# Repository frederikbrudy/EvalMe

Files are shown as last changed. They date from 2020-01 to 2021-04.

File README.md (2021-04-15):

#EvalMe: Exploring the Value of New Technologies for In Situ Evaluation of Learning Experiences

Repository accompanying the ACM CHI 2021 publication **EvalMe: Exploring the Value of New Technologies for In Situ Evaluation of Learning Experiences.** 
Auhtors: *Susan Lechelt, Frederik Brudy, Nicolai Marquardt, Yvonne Rogers.*
Published in Proceedings of the ACM Conference on Human Factors in Computing Systems 2021 (ACM CHI '21), May 8–13, 2021, Yokohama, Japan.
DOI: https://doi.org/10.1145/3411764.3445749

#Contents
- [EvaleMe-Desktop](EvaleMe-Desktop) contains the code for the Electron app for the EvalMe Desktop application
- [EvalMe-Hardware](EvalMe-Hardware) contains the Arduino code for both Sender and Receiver
  - [EvalMe-encoderButton-Neopixelring-rf95-client-Mega.V2](EvalMe-Hardware\EvalMe-encoderButton-Neopixelring-rf95-client-Mega.V2) is the code for the sender
  - [EvalMe-rf95_reliable_datagram_server.V2](EvalMe-Hardware\EvalMe-rf95_reliable_datagram_server.V2) is the code for the receiver
  - [Case-Receiver](EvalMe-Hardware/Case-Receiver) contains the 3D printing files for the receiver case. 
  - [Case-Sender](EvalMe-Hardware/Case-Sender) contains the 3D printing files for the sender case.

# EvalMe hardware

The system consists of two parts, one Sender (large box) and one Receiver part (small box) as described in the publication. The receiver is simply an Arduino Uno, with a LoRa shield stacked on top of it, and mounted to the bottom part of the small box.

The sender needs more assembling, which is detailed below.

It might make sense to assemble some / all of these on a breadboard before soldering and test whether the code and hardware is working correctly.

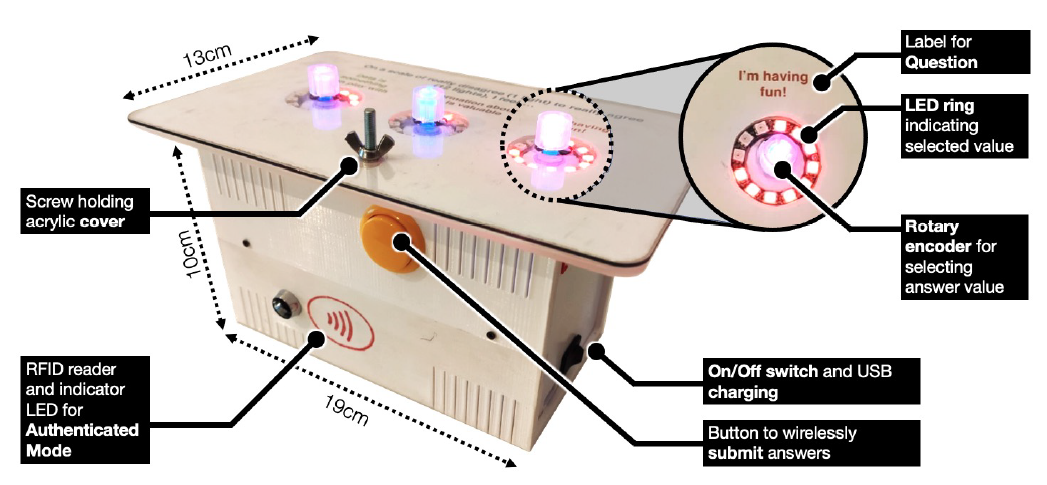
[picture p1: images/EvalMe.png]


https://www.youtube.com/watch?v=0FNkCVAWlew

## Parts for sender

The sender device consists of multiple components:

- Arduino Mega
- RFID Module (Adadfruit PN532 Breakout Board)
- PowerBoost 1000C
- Toggle switch for power
- 3x 12 LED Neopixel rings
- 3x Rotary Encoder with RGB LED and pushbutton
- Arduino Mega ProtoShield to solder the connections
- LoRa shield. Stacks on top of the Mega Proto Shield.
- Push button
- 5mm blue LED and silver LED holder. 100 Ohm+ resistor
- Several 2-wire click connectors (for LED, PowerBoost Enable, PowerBoost-to-Arduino connection, pushbutton)
- Several 3-wire click connectors (for 5V and GND for rotary encoder, Neopixel rings)
- Several 6-wire click connectors (for data connection for rotary encoder, RFID shield)

## Cases
The 3D printing files can be found in [Case-Receiver](EvalMe-Hardware/Case-Receiver) as well as [Case-Sender](EvalMe-Hardware/Case-Sender)

## General structure
The Arduino Mega and the PowerBoost are screwed to the bottom part of the Sender casing. There are mounts in the base for both. Small screws should be used.

The proto shield (see below) is stacked on top of the Arduino. The LoRa shield is stacked on top of the proto shield.

The RFID module is placed upright towards the front where the RFID symbol is. Use e.g. double-sided tape or Velcro to hold it in place. The battery is placed behind the RFID module.

A large blue LED is screwed with the silver LED mount to the hole to the left of the RFID symbol. Connect using a minimum 100 Ohm resistor between LED and power.

A push button is connected to the right of the RFID symbol. 

The connections between the Proto Shield and all other components should be made with click-connectors. They are either 2-wire, 3-wire, or 6-wire and have a male and female part. The wires coming from e.g. the female connector are soldered to the proto shield, the wires coming from e.g. the male connector are soldered to the components.
 The connection holes for the wires on each side are labelled with numbers on the back that correspond to the same connection on the other clip. You need to crimp the wires and clip then into the male/female connectors. 

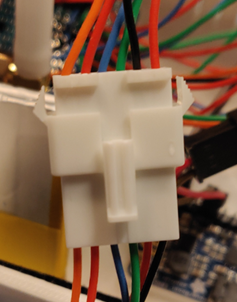
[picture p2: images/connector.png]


## Proto Shield

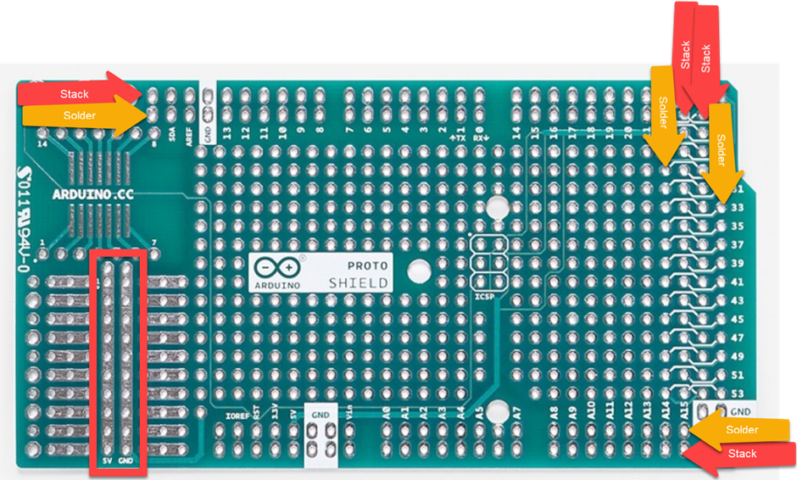
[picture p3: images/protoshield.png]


Generally, all connections to components should be made through the Proto Shield (see image above). Sacking headers must be soldered to the Proto Shield. Stacking headers (see following image) are the ones with long legs at the bottom (to stack on top of the Arduino), and female connectors at the top (to stack other shields on top, i.e. the LoRa shield).

The stacking headers are soldered to the rows / columns of through-holes marked in red &quot;Stack&quot; above (basically so that they&#39;ll stack properly on top of the Arduino). Wires connecting to the click-connectors (which then connect to other components) are then soldered to the through-holes marked with &quot;Solder&quot;.

Note that the Proto Shield has many through-holes connected to GND and 5V on the left (marked with the red rectangle). These can be used to connect the GND and 5V of pushbuttons, LED rings, and RFID board, etc.

Note the block in the front, that&#39;s the one to use for the centre connection of the LoRa module (see description below).

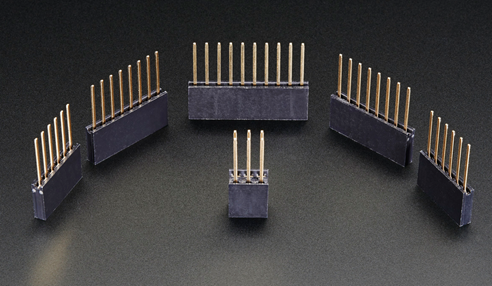
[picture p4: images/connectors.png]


## LoRa shield

The LoRa shield is stacked on top of the Proto Shield. The LoRa shield requires the six pins in the middle of the board (circled in red below, labelled with ICSP) to connected to the Arduino as well, so these headers must be soldered to the Proto Shield as well. There are 2x3 headers (see image above) that fit here. **Attention:** Here the female connectors are facing down towards the Arduino board and the male pins are facing up—that&#39;s the opposite way as all other pins, so the headers must be adjusted accordingly.

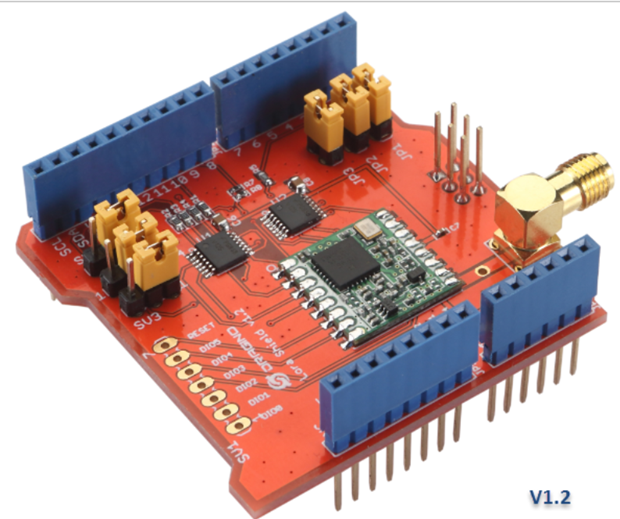
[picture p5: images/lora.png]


## PowerBoost 1000C

Connect the GROUND and ENable pin on the PowerBoost to the toggle switch. This allows to turn the 5V output of the PowerBoost off/on. There should be black switches that fit nicely into the side-plate of the large case. Note: It might be that the labelling on the switch is inverted to the behaviour of the PowerBoost (i.e. when the switch is set to I the output is off, when set to O the output is on). In this case carefully use a carpenter knife and scratch out the labelling on the button.

Connect the other GND of the PowerBoost to the Arduino GND and the 5V to Vin on the Arduino ( **NOT** to 5V on the Arduino).

PowerBoost GND -> One toggle switch pin
 PowerBoost EN -> Other toggle switch pin
 Make these connections using a 2-wire click connector

PowerBoost GND -> Arduino GND
 PowerBoost 5V -> Arduino Vin
 You can make the 5V/GND connection using jumper wires or a 2-wire click connector

You might need to solder headers on to the PowerBoost.

Make sure you&#39;re using the 1000C, not the 500 and not the basic. The C indicates Charger, so it has a micro USB connection to charge the connected battery and/or power directly without a battery. Connect the battery only after you finished the general assembly of everything.

Some of the PowerBoosts are faulty and the LED labelled LOW lights up when the output is switched to off (not to be confused with the CHARGE LED). In this case gently cut the connection of the LOW LED using a carpenter knife or similar to turn it off entirely.

## Rotary encoders

Not all the encoders are yet soldered to the breakout boards. When assembling them please note that the red breakout boards are two-sided, labelled RG and RGB. We have RGB LEDs inside the pushbuttons, so use the RGB side: When assembling the rotary encoders / pushbuttons they should be inserted into the RGB side of the breakout board. In other words, when holding the button/encoder normally up, the RGB side of the breakout board is facing up. Some of them are already assembled, so just check how it&#39;s done there.

The following indicates the connections from the encoders to the Arduino.
 For the GND and 5V connections you can use a 3-wire click connector shared between the three encoders. For the other connections you can use a 6-wire click connector fore each button.
 For example, the 6-wire A-1 connector means a 6-wire click connector A, hole 1.

### Button 1

| | Encoder | Proto Shield | Connector |
|---|---|---|---|
| These pins are on the side with the 3 pins | B | 22 | 6-wire A-1 |
| | C | GROUND | 3-wire click connector shared between all encoders |
| | A | 18 | 6-wire A-2 |
| These pins are on the side with the 5 pins | R | 15 | 6-wire A-3 |
| | G | A14 | 6-wire A-4 |
| | SW | 14 | 6-wire A-5 |
| | B | 16 | 6-wire A-6 |
| | + | 5 Volt | 3-wire click connector shared between all encoders |

<!--![images/wiring-button1.png](images/wiring-button1.png)-->

### Button 2
| | Encoder | Proto Shield | Connector |
|---|---|---|---|
| These pins are on the side with the 3 pins | B | 23 | 6-wire B-6 |
| | C | GROUND | 3-wire click connector shared between all encoders |
| | A | 19 | 6-wire B-6 |
| These pins are on the side with the 5 pins | R | 29 | 6-wire B-6 |
| | G | 28 | 6-wire B-6 |
| | SW | 31 | 6-wire B-6 |
| | B | 30 | 6-wire B-6 |
| | + | 5 Volt | 3-wire click connector shared between all encoders |

<!-- ![images/wiring-button2.png](images/wiring-button2.png)--> 

### Button 3

| | Encoder | Proto Shield | Connector |
|---|---|---|---|
| These pins are on the side with the 3 pins | B | 24 | 6-wire C-6 |
| | C | GROUND | 3-wire click connector shared between all encoders |
| | A | 3 | 6-wire C-6 |
| These pins are on the side with the 5 pins | R | 32 | 6-wire C-6 |
| | G | 33 | 6-wire C-6 |
| | SW | 34 | 6-wire C-6 |
| | B | 35 | 6-wire C-6 |
| | + | 5 Volt | 3-wire click connector shared between all encoders |

<!--![images/wiring-button3.png](images/wiring-button3.png)-->

After assembling, uploading the code, and testing the mapping of the rotary encoder to the NeoPixel rings you might need to switch around which click connector from which button connects to which corresponding connector on the proto shield. But that&#39;s just a matter of flipping them to another.

## RFID module

Use the following PIN mapping. Images below indicate the pins on the RFID module. Use a 6-wire click connector.

| **RFID module PIN** | **Arduino PIN / Proto Shield** |
| --- | --- |
| 2 | 46 |
| 3 | 47 |
| SDA (3 pins to the right of PIN 13) | 20 (SDA) |
| SCL (next to the above) | 21 (SCL) |
| GND | GND (can be to the dedicated GND section on the left of the proto shield) |
| 5V | 5V (can be to the dedicated GND section on the left of the proto shield) |

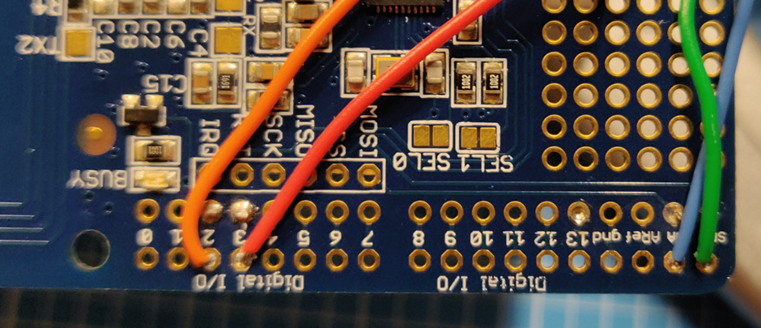
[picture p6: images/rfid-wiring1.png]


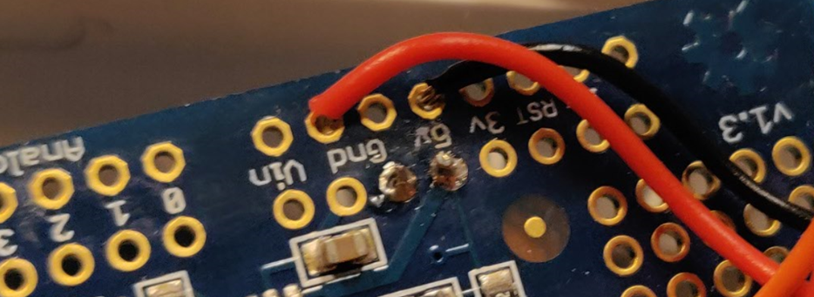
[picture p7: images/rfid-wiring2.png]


## NeoPixel LED rings

There are 3 NeoPixel rings with 12 LEDs each. They are connected in series to Arduino PIN 40, 5V, and GND. To allow assembly, there should be a 3-wire click connector used between each of them, so that DO (data out) of the previous ring is connected to DI (data in) of the next.

Arduino PIN 40 -> Ring 1 DI (data in)

Ring 1 DO (data out) -> Ring 2 DI

Ring 2 DO -> Ring 3 DI

5V &amp; GND from Arduino to the first ring 5v&amp;GND next to DI.
 5V &amp; GND next to DO of ring 1 then to the 5V and GND next to the DI of the ring 2 and so on.

Use small screws to mount the rings to the case. You might need to drill one of the holes again, as the holes on the case might not fit perfectly. **Note:** When using metal screws, they might short circuit two of the pixels and cause a reset of the Arduino / erratic behaviour. Use small drops of superglue to create a small plastic film over the metal parts that are touched by the screws. Let it dry and then insert the screws. I have done this already for the rings used in the half-assembled prototype.

## Pushbutton and LED

A large (5mm) blue LED is screwed with the silver LED mount to the hole to the left of the RFID symbol. Add a minimum 100 Ohm resistor between LED and Arduino.

A push button is connected to the right of the RFID symbol. Use one with a flat backside, not the one that sticks out \&gt;3cm. There should be one ready on the desk. No resistor needed for the button

| **Part** | **Arduino / Proto Shield** |
| --- | --- |
| LED short leg | GND (add a >100 Ohm resistor in series) |
| LED long leg | 38 |
| Button PIN 1 | 42 |
| Button PIN 2 | GND |

Code for the Arduino can be found in the folder [EvalMe Hardware](EvalMe Hardware)

Once everything is assembled, upload code as follows:

- [EvalMe-encoderButton-Neopixelring-rf95-client-Mega.V2](EvalMe-Hardware\EvalMe-encoderButton-Neopixelring-rf95-client-Mega.V2) to the Arduino Mega in the Sender
- [EvalMe-rf95_reliable_datagram_server.V2](EvalMe-Hardware\EvalMe-rf95_reliable_datagram_server.V2) to the Arduino Uno in the Receiver

You can test it by opening the serial monitor on the receiver / Uno and power up the sender. Then enter the following text in serial monitor and send it to the Arduino Uno:

`REQUIRE_NO_AUTH` and `SET_COUNTER_MAX:12` 
This will set some initial parameters in the Mega's EEPROM.
 Afterwards play around with the encoders to check whether the LED&#39;s on the rings light up correctly. Press the button to send the data. It should be displayed in the Serial Monitor on the receiver / Uno.

To test the RFID, send the following to the receiver's / Uno's serial monitor `REQUIRE_AUTH` 
 All LEDs on top of the sender should turn off and the blue LED should blink. Use e.g. your student ID card to &quot;log in&quot; and then the encoders are usable.

## License
MIT license

**EvalMe: Exploring the Value of New Technologies for In Situ Evaluation of Learning Experiences.**
*Susan Lechelt, Frederik Brudy, Nicolai Marquardt, Yvonne Rogers.*
Published in Proceedings of the ACM Conference on Human Factors in Computing Systems 2021 (ACM CHI '21), May 8–13, 2021, Yokohama, Japan.
DOI: https://doi.org/10.1145/3411764.3445749

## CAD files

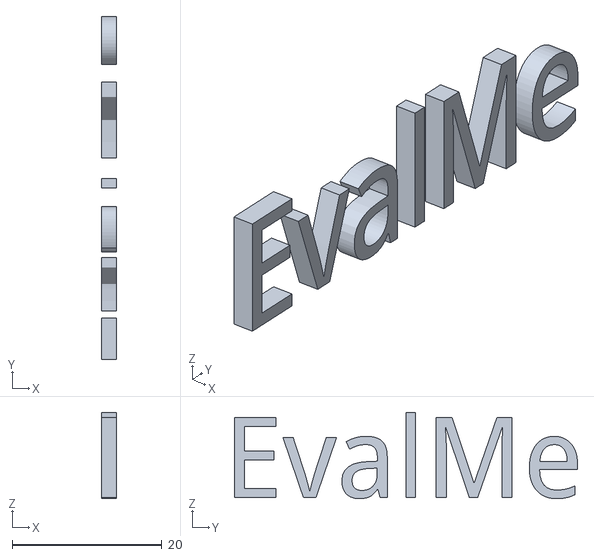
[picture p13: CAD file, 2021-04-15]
EvalMe-Hardware/Case-Receiver/receiver.V1.front.writing-EvalMe.stl
2.02 x 45.8 x 11.6

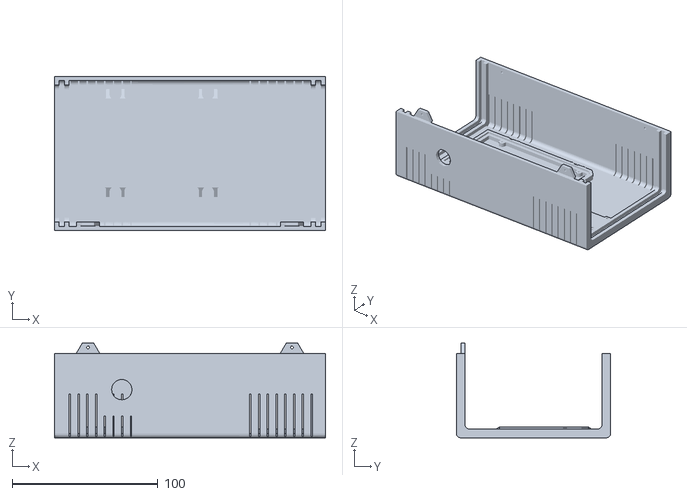
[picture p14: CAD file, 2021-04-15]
EvalMe-Hardware/Case-Sender/U_Box_V103.bottom.V2-without logo.stl
186.0 x 106.0 x 64.9

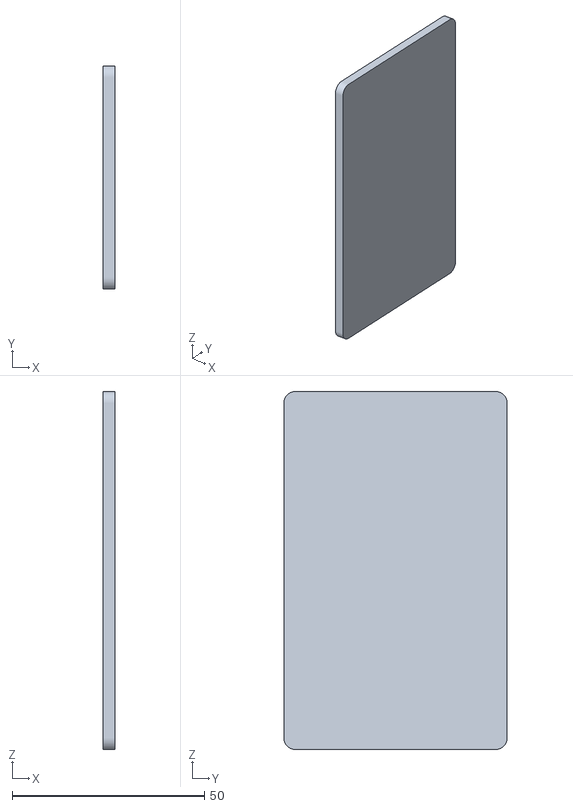
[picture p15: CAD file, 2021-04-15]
EvalMe-Hardware/Case-Receiver/receiver.V1.front.stl
3.00 x 58.1 x 93.1

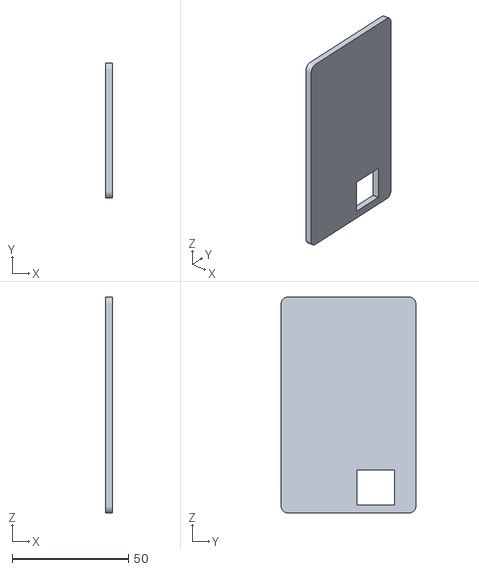
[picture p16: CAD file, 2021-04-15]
EvalMe-Hardware/Case-Receiver/receiver.V1.back-with cutout.stl
3.00 x 58.1 x 93.1

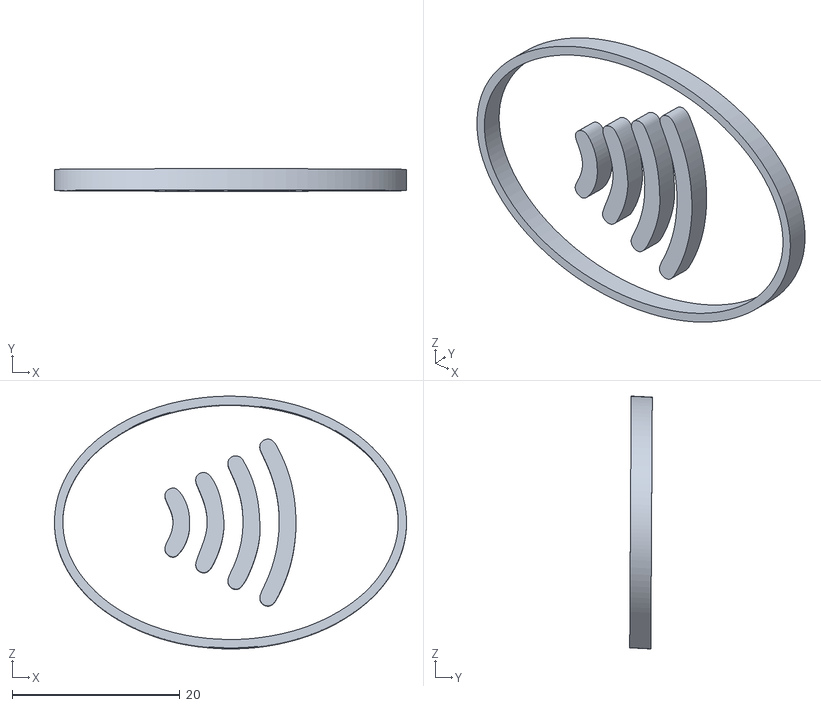
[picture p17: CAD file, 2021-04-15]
EvalMe-Hardware/Case-Sender/U_Box_V103.bottom.V2-only logo.stl
42.0 x 2.70 x 30.1

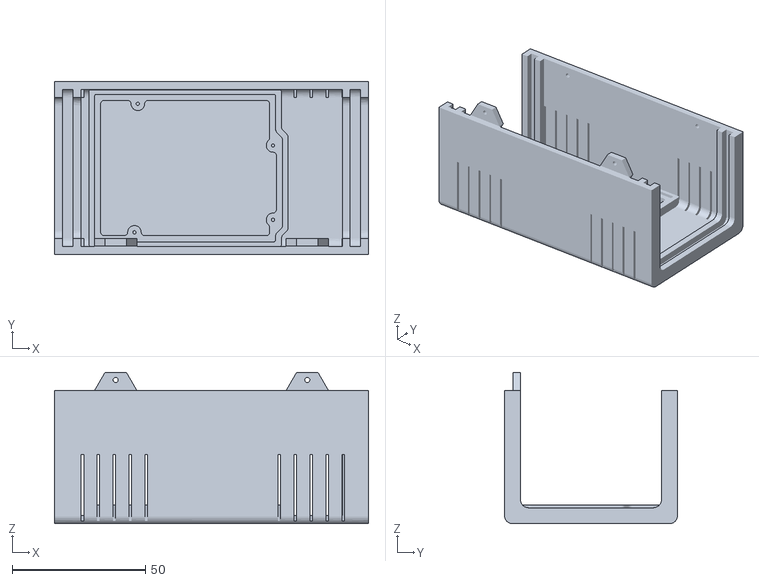
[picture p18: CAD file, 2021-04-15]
EvalMe-Hardware/Case-Receiver/receiver.V1.bottom-with mount.stl
118.0 x 65.0 x 56.9

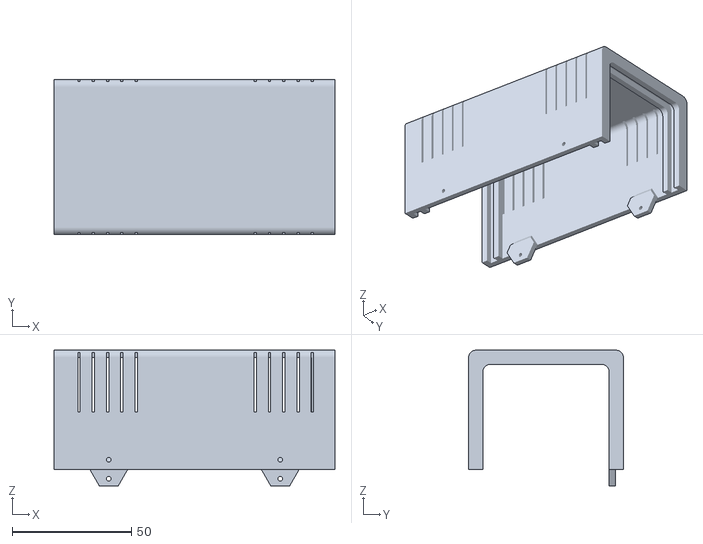
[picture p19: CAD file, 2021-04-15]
EvalMe-Hardware/Case-Receiver/receiver.V1.top.stl
118.0 x 65.0 x 56.9

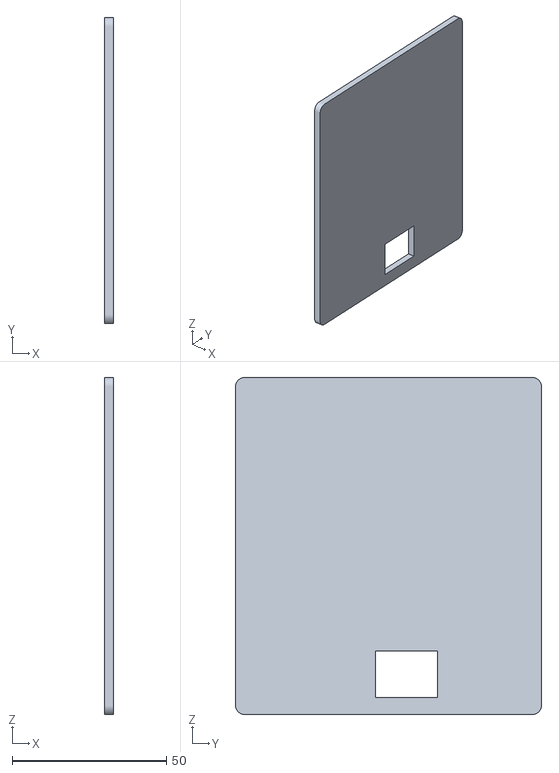
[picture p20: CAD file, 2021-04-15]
EvalMe-Hardware/Case-Sender/U_Box_V103.back.V1.stl
3.00 x 99.1 x 109.1

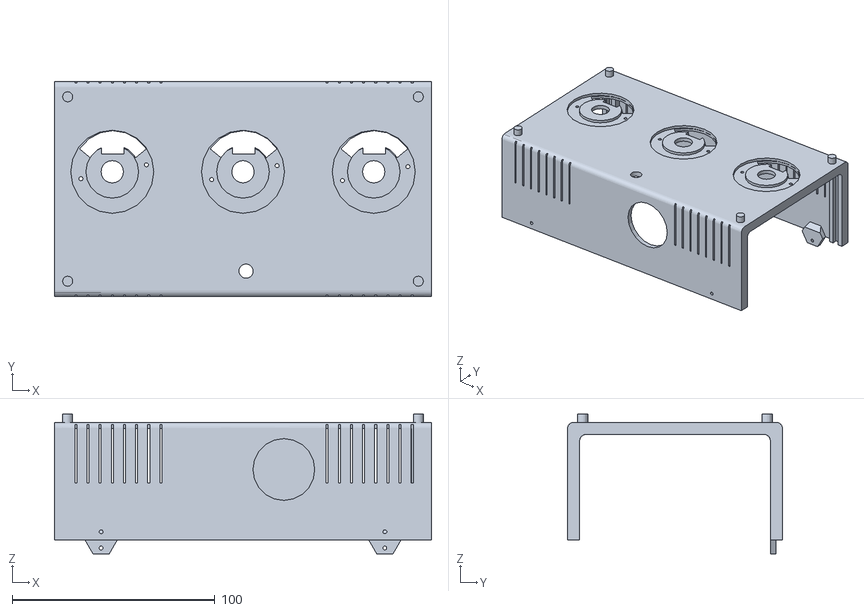
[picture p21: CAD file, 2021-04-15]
EvalMe-Hardware/Case-Sender/U_Box_V103.top.V6.stl
186.0 x 106.0 x 69.0

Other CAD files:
EvalMe-Hardware/Case-Sender/U_Box_V103.front-noFont.V1 with cutouts, no LED-hole.stl
EvalMe-Hardware/Case-Sender/U_Box_V103.front-FontOnly.V1.stl

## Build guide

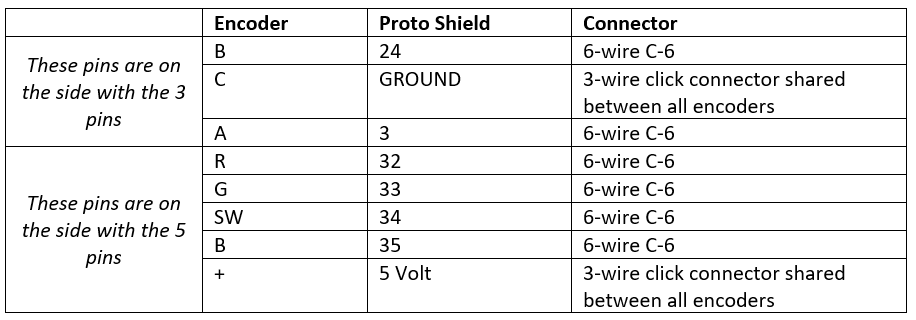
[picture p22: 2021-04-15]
images/wiring-button3.png

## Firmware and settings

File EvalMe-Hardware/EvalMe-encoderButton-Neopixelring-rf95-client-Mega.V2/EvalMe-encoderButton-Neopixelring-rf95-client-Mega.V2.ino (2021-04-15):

// HARDWARE CONNECTIONS
// connect a rotary encoder to your Arduino using these pins:

// Rotary encoder pin A to digital pin 3*
// Rotary encoder pin B to analog pin 3
// Rotary encoder pin C to ground

// This sketch implements software debounce, but you can further
// improve performance by placing 0.1uF capacitors between
// A and ground, and B and ground.

// If you wish to use the RGB LED and button functions of
// SparkFun part number COM-10982, use the following connections:

// Rotary encoder pin 1 (red cathode) to digital pin 10
// Rotary encoder pin 2 (green cathode) to analog pin 1
// Rotary encoder pin 3 (button) to digital pin 4
// Rotary encoder pin 4 (blue cathode) to digital pin 5
// Rotary encoder pin 5 (common anode) to VCC (3.3V or 5V)

// Note that because this is a common anode device,
// the pushbutton requires an external 1K-10K pullDOWN resistor
// to operate.

// * Pins marked with an asterisk should not change because
// they use interrupts on that pin. All other pins can change,
// see the constants below.

// SERIAL MONITOR

// Run this sketch with the serial monitor window set to 9600 baud.

// HOW IT WORKS

// The I/O pins used by the rotary encoder hardware are set up to
// automatically call interrupt functions (rotaryIRQ and buttonIRQ)
// each time the rotary encoder changes states.

// The rotaryIRQ function transparently maintains a counter that
// increments or decrements by one for each detent ("click") of
// the rotary encoder knob. This function also sets a flag
// (rotary_change) to true whenever the counter changes. You can
// check this flag in your main loop() code and perform an action
// when the knob is turned.

// There is also code in the main loop() that keeps track
// of whether the button is currently being held down and for
// how long. This is useful for "hold button down for five seconds
// to power off"-type situations, which cannot be handled by
// interrupts alone because no interrupts will be called until
// the button is actually released.

// Uses the PinChangeInt library by Lex Talionis,
// download from http://code.google.com/p/arduino-pinchangeint/


#define HALT_ON_ERROR false

#include <EEPROM.h> 

////////////////////////////////////////////////
//Rotary encoder with RGB pushbutton
////////////////////////////////////////////////

// Load the PinChangeInt (pin change interrupt) library
#include <PinChangeInt.h>


///////////// confirm button

#define BUTTON_PIN 42

/////////////rotary encoder 1
#define ROT_B 22        // rotary B 
#define ROT_A 18          // rotary A IRQ

#define ROT_LEDR 15      // red LED
#define ROT_LEDG A14     // green LED
#define ROT_SW 14         // rotary puhbutton
#define ROT_LEDB 16       // blue LED

/////////////rotary encoder 2
#define ROT2_B 23        // rotary B 
#define ROT2_A 19          // rotary A IRQ

#define ROT2_LEDR 29      // red LED
#define ROT2_LEDG 28     // green LED
#define ROT2_SW 31         // rotary puhbutton
#define ROT2_LEDB 30       // blue LED

///////////rotary encoder 3

#define ROT3_B 24        // rotary B 
#define ROT3_A 3          // rotary A IRQ

#define ROT3_LEDR 32      // red LED
#define ROT3_LEDG 33     // green LED
#define ROT3_SW 34         // rotary puhbutton
#define ROT3_LEDB 35       // blue LED

// RGB LED colors (for common anode LED, 0 is on, 1 is off)
#define OFF B111
#define RED B110
#define GREEN B101
#define YELLOW B100
#define BLUE B011
#define PURPLE B010
#define CYAN B001
#define WHITE B000


// low battery indicator
#define LBO_PIN 52 // PowerBoost 1000C low battery indicator
#define LOW_BATTERY_LED 53


/////////// confirm button
volatile boolean confirm_button_pressed = false; // will turn true if the button has been pushed
volatile boolean confirm_button_released = false; // will turn true if the button has been released (sets button_downtime)
volatile unsigned long confirm_button_downtime = 0L; // ms the button was pushed before release
static boolean confirm_button_down = false;
static unsigned long int confirm_button_down_start, confirm_button_down_time;

/////////// rotary encoder 1
// Global variables that can be changed in interrupt routines
volatile int rotary_counter = 0; // current "position" of rotary encoder (increments CW)
volatile boolean rotary_change = false; // will turn true if rotary_counter has changed
//volatile boolean button_pressed = false; // will turn true if the button has been pushed
//volatile boolean button_released = false; // will turn true if the button has been released (sets button_downtime)
//volatile unsigned long button_downtime = 0L; // ms the button was pushed before release

// "Static" variables are initalized once the first time
// that loop runs, but they keep their values through
// successive loops.

static unsigned char ledColor = BLUE; //LED color
//static boolean button_down = false;
//static unsigned long int button_down_start, button_down_time;


////////// rotary encoder 2
int counter2_ledsOn = 0;
// Global variables that can be changed in interrupt routines
volatile int rotary2_counter = 0; // current "position" of rotary encoder (increments CW)
volatile boolean rotary2_change = false; // will turn true if rotary_counter has changed
//volatile boolean button2_pressed = false; // will turn true if the button has been pushed
//volatile boolean button2_released = false; // will turn true if the button has been released (sets button_downtime)
//volatile unsigned long button2_downtime = 0L; // ms the button was pushed before release

static unsigned char ledColor2 = BLUE; //LED color
//static boolean button2_down = false;
//static unsigned long int button2_down_start, button2_down_time;



////////// rotary encoder 3
int counter3_ledsOn = 0;
// Global variables that can be changed in interrupt routines
volatile int rotary3_counter = 0; // current "position" of rotary encoder (increments CW)
volatile boolean rotary3_change = false; // will turn true if rotary_counter has changed
//volatile boolean button3_pressed = false; // will turn true if the button has been pushed
//volatile boolean button3_released = false; // will turn true if the button has been released (sets button_downtime)
//volatile unsigned long button3_downtime = 0L; // ms the button was pushed before release

static unsigned char ledColor3 = BLUE; //LED color
//static boolean button3_down = false;
//static unsigned long int button3_down_start, button3_down_time;







////////////////////////////////////////////////
//Neopixel stuff. 
////////////////////////////////////////////////
#include <Adafruit_NeoPixel.h>
int COUNTER_MIN = 0;
int COUNTER_MAX = 12;
/////////// ring 1
#define RING1_NEOPIXEL_PIN 40
#define RING_PIXEL_COUNT 12
#define RING_COUNT 3
int ring1_counter_ledsOn = 0;

/////////// ring 2
//#define RING2_NEOPIXEL_PIN 41
//#define RING2_PIXEL_COUNT 12
int ring2_counter_ledsOn = 0;

/////////// ring 3
//#define RING3_NEOPIXEL_PIN 42
//#define RING3_PIXEL_COUNT 12
int ring3_counter_ledsOn = 0;

Adafruit_NeoPixel rings = Adafruit_NeoPixel(RING_PIXEL_COUNT*RING_COUNT, RING1_NEOPIXEL_PIN, NEO_GRB + NEO_KHZ800);
//Adafruit_NeoPixel ring2 = Adafruit_NeoPixel(RING2_PIXEL_COUNT, RING2_NEOPIXEL_PIN, NEO_GRB + NEO_KHZ800);
//Adafruit_NeoPixel ring3 = Adafruit_NeoPixel(RING3_PIXEL_COUNT, RING3_NEOPIXEL_PIN, NEO_GRB + NEO_KHZ800);



// IMPORTANT: To reduce NeoPixel burnout risk, add 1000 uF capacitor across
// pixel power leads, add 300 - 500 Ohm resistor on first pixel's data input
// and minimize distance between Arduino and first pixel.  Avoid connecting
// on a live circuit...if you must, connect GND first.

uint32_t red = rings.Color(255, 0, 0);
uint32_t green = rings.Color(0, 255, 0);
uint32_t blue = rings.Color(0, 0, 255);
uint32_t purple = rings.Color(128, 0, 128);
uint32_t yellow = rings.Color(255, 100, 0);
uint32_t off = rings.Color(0, 0, 0);
uint32_t white = rings.Color(255, 255, 255);
uint32_t cyan = rings.Color(0, 255, 255);

void setRingPixelColor(uint8_t ringNumber, uint32_t pixelNumber, uint32_t color){
  rings.setPixelColor(pixelNumber+(ringNumber*RING_PIXEL_COUNT), color);
}

void setRingPixelColorAll(uint32_t pixelNumber, uint32_t color){
  for (int ring = 0; ring < RING_COUNT; ring++){
    rings.setPixelColor(pixelNumber+(ring*RING_PIXEL_COUNT), color);
  }
}

void clearRing(uint8_t ringNumber){
  for (int pixelNumber = 0; pixelNumber < RING_PIXEL_COUNT; pixelNumber++){
    rings.setPixelColor(pixelNumber+(ringNumber*RING_PIXEL_COUNT), off);
  }
  rings.show();
}

uint32_t ledColorToNeopixelColor(uint32_t color){
  switch(color){
    case OFF:
      return off;
      break;
    case RED:
      return red;
      break;
    case GREEN:
      return green;
      break;
    case YELLOW:
      return yellow;
      break;
    case BLUE:
      return blue;
      break;
    case PURPLE:
      return purple;
      break;
    case CYAN:
      return cyan;
      break;
    case WHITE:
      return white;
      break;
    default: 
      return red;
      break;
  }
}

////////////////////////////////////////////////
//Buffer stuff. Used when data cannot be sent for later sending. Stores the last ten submissions
////////////////////////////////////////////////
#include "CircularBuffer.h"

// the type of the record is unsigned long: we intend to store milliseconds
// the buffer can contain up to 10 records
// the buffer will use a byte for its index to reduce memory footprint
CircularBuffer<unsigned long, 10> fifo;
CircularBuffer<String, 10> fifoStr;


////////////////////////////////////////////////
//LoRa communication stuff
////////////////////////////////////////////////
// Based on example: rf95_reliable_datagram_client.ino
// Don't forget to set the frequency of the board when using the RadioHead library
//The RadioHead Library simplifies communication between the Arduino Board and the LoRa Shield.
//We can find it here: http://www.airspayce.com/mikem/arduino/RadioHead/ To use it in your project 
//you just have to copy it in your Arduino project folder (next to your main Arduino project file .ino).
//Compile Notice:
//Check if you have set the right frequency:After putting the library in the right place, 
//you have to also modify the frequency to the frequency you want to use, the position of this is
//setFrequency() in the file: arduino-xxx\libraries\RadioHead\RH_RF95.cpp;
//we're using this LoRa Shield: https://wiki.dragino.com/index.php?title=Lora_Shield

#include <RHReliableDatagram.h>
#include <RH_RF95.h>
#include <SPI.h>

#define CLIENT_ADDRESS 5
#define SERVER_ADDRESS 3

// Singleton instance of the radio driver
RH_RF95 driver;
//RH_RF95 driver(5, 2); // Rocket Scream Mini Ultra Pro with the RFM95W

// Class to manage message delivery and receipt, using the driver declared above
RHReliableDatagram manager(driver, CLIENT_ADDRESS);

//uint8_t data[] = "Hello World!";
uint8_t data[64] = "";
// Dont put this on the stack:
uint8_t buf[RH_RF95_MAX_MESSAGE_LEN];

int counter = 0;
#include <string.h>

////////////////////////////////////////////////
// RFID stuff for for the adafrui NFC shield iwth I2C connection
////////////////////////////////////////////////
#include <Wire.h>
#include <Adafruit_PN532.h>
// If using the breakout or shield with I2C, define just the pins connected
// to the IRQ and reset lines.  Use the values below (2, 3) for the shield!
#define PN532_IRQ   46
#define PN532_RESET 47  // Not connected by default on the NFC Shield
// Or use this line for a breakout or shield with an I2C connection:
Adafruit_PN532 nfc(PN532_IRQ, PN532_RESET);

bool requiresAuthentication = false;
uint8_t ctrl_requireAuth[] = "REQUIRE_AUTH";
uint8_t ctrl_requireNoAuth[] = "REQUIRE_NO_AUTH";
int eeprom_address_AuthReq = 0;
unsigned long start_time;
unsigned long end_time;
unsigned long delta;

#define eeprom_address_CounterStart 10
int eeprom_address_CounterMin = eeprom_address_CounterStart;
int eeprom_address_CounterMax = 50;//eeprom_address_CounterStart + sizeof(int);;
uint8_t ctrl_SetCounterStart[] = "SET_COUNTER";

uint8_t ctrl_SetMin1[] = "SET_COUNTER_MIN:1";

uint8_t ctrl_SetMax3[] = "SET_COUNTER_MAX:03";
uint8_t ctrl_SetMax4[] = "SET_COUNTER_MAX:04";
uint8_t ctrl_SetMax5[] = "SET_COUNTER_MAX:05";
uint8_t ctrl_SetMax7[] = "SET_COUNTER_MAX:07";
uint8_t ctrl_SetMax10[] = "SET_COUNTER_MAX:10";
uint8_t ctrl_SetMax12[] = "SET_COUNTER_MAX:12";

#define RFID_LED 38
void setup()
{
  //start serial communication
  Serial.begin(9600); // Use serial for debugging
  Serial.println("Begin setup");

  EEPROM.get(eeprom_address_AuthReq, requiresAuthentication);
  Serial.print("READ from Eeprom requiresAuthentication: ");
  Serial.println(requiresAuthentication);
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
void loop()
{
  int lboVal = digitalRead(LBO_PIN);
//  Serial.print("lbo val: ");
//  Serial.println(lboVal);
  if(lboVal){
    digitalWrite(LOW_BATTERY_LED, HIGH);
//    Serial.println("LOW_BATTERY_LED on");
  }
  else{
    digitalWrite(LOW_BATTERY_LED, LOW);
//    Serial.println("LOW_BATTERY_LED off");
  }
  
  if (manager.available())
  {
    // Wait for a message addressed to us from the client
    uint8_t len = sizeof(buf);
    uint8_t from;
    if (manager.recvfromAck(buf, &len, &from))
    {
      Serial.print("#TYPE:INCOMING;FROM:0x");
      Serial.print(from, HEX);
      Serial.print(";");
      Serial.println((char*)buf);

      if(strcmp(buf, ctrl_requireAuth) == 0 || strcmp(buf, ctrl_requireNoAuth) == 0){
        if(strcmp(buf, ctrl_requireAuth) == 0){
          Serial.println("REQUIRE_AUTH activated");
          requiresAuthentication = true;
        }
        else if(strcmp(buf, ctrl_requireNoAuth) == 0){
          Serial.println("REQUIRE_AUTH deactivated");
          requiresAuthentication = false;
        }
        //write to eeprom
        EEPROM.update(eeprom_address_AuthReq, requiresAuthentication);
        Serial.print("Written to eeprom requiresAuthentication: ");
        Serial.println(requiresAuthentication);
      }
      else if(strncmp(buf, ctrl_SetCounterStart, 11) == 0){
//        don't use substring, but use the array positions
//        String countStr = inputString.substring(16);
//        int count = countStr.toInt();


//        if(strcmp(buf, ctrl_SetMin) == 0){
//          Serial.print("SET_COUNTER_MIN: ");
//          Serial.println(count);
//          EEPROM.update(eeprom_address_CounterMin, count);
//          COUNTER_MIN = count;
//        }
        int countMax;
        bool maxChanged = false;
        if(strcmp(buf, ctrl_SetMax3) == 0){
          Serial.println("SET_COUNTER_MAX:03");
          countMax = 3;
          maxChanged = true;
        }
        else if(strcmp(buf, ctrl_SetMax4) == 0){
          Serial.println("SET_COUNTER_MAX:04");
          countMax = 4;
          maxChanged = true;
        }
        else if(strcmp(buf, ctrl_SetMax5) == 0){
          Serial.println("SET_COUNTER_MAX:05");
          countMax = 5;
          maxChanged = true;
        }
        else if(strcmp(buf, ctrl_SetMax7) == 0){
          Serial.println("SET_COUNTER_MAX:07");
          countMax = 7;
          maxChanged = true;
        }
        else if(strcmp(buf, ctrl_SetMax10) == 0){
          Serial.println("SET_COUNTER_MAX:10");
          countMax = 10;
          maxChanged = true;
        }
        else if(strcmp(buf, ctrl_SetMax12) == 0){
          Serial.println("SET_COUNTER_MAX:12");
          countMax = 12;
          maxChanged = true;
        }

        if(maxChanged){
          COUNTER_MAX = countMax;

          EEPROM.update(eeprom_address_CounterMax, COUNTER_MAX);

          Serial.print("maxChanged. new max: ");
          Serial.print(COUNTER_MAX);
          Serial.print(". EEPROM address: ");
          Serial.println(eeprom_address_CounterMax);
        }
      }



      // Send a reply back to the originator client
//      if (!manager.sendtoWait(data, sizeof(data), from))
//        Serial.println("#TYPE:ERROR;DATA:sendtoWait failed");
    }
  }

//  printDeltaAndRestart("managaer available");

  //if there is data in the queue try to send it
  for (int i=fifoStr.size(); i>0; i--) {
    // prints current buffer size
    Serial.println("UNSENT DATA");
    Serial.print("    ");
    Serial.print(i);
    Serial.print(": ");
    // retrieves the last added button click and removes the event
    // this outputs the events starting from the most recent
    // switching from pop() to shift() the events would be printed
    // in chronological order, starting from the least recent
    Serial.println(fifoStr.last());
//    uint8_t data[]
    //try to send

    String tryString = fifoStr.last();
    char data2[tryString.length()];
    tryString.toCharArray(data2, (tryString.length()+1));
    Serial.print("        ");
    Serial.print("RETRYING FOR: ");
    Serial.println(data2);

    if (manager.sendtoWait(data2, sizeof(data2), SERVER_ADDRESS))
    {
      // Now wait for a reply from the server
      uint8_t len = sizeof(buf);
      uint8_t from;   
      if (manager.recvfromAckTimeout(buf, &len, 2000, &from))
      {
        Serial.print("        ");
        Serial.print("got reply from : 0x");
        Serial.print(from, HEX);
        Serial.print(": ");
        Serial.println((char*)buf);
        fifoStr.pop();
        ledColor = BLUE;
        ledColor2 = BLUE;
        ledColor3 = BLUE;
        invalidateLEDs();
      }
      else
      {
        Serial.println("No reply, is rf95_reliable_datagram_server running?");
//        fifoStr.push(str);
      }
    }
    else{
      Serial.println("sendtoWait failed");
//      fifoStr.push(str);
    }
    
//    if(sendData(data2)){
//      //if successfully sent, then remove it from the 
////      fifoStr.pop();
//    }
  }
  //check if the queue is full. if it is go into error mode until the data can be dumped
  if(fifoStr.isFull()){
    //TODO don't go into error loop, but keep trying to send data
    error(red, 3);
    return;
  }

//  printDeltaAndRestart("fifo processed");

  start_time = micros();

  if(requiresAuthentication){
    processRfid();
  }

//  printDeltaAndRestart("RFID processed");
  bool authenticated = true;
  if(requiresAuthentication){
    //allow voting if ID required
    //TODO
    if(!cardPresent){
      ledColor = PURPLE;
      ledColor2 = PURPLE;
      ledColor3 = PURPLE;
      authenticated = false;
    }
    else{
      ledColor = BLUE;
      ledColor2 = BLUE;
      ledColor3 = BLUE;
    }
    
  }
  else{
    ledColor = BLUE;
    ledColor2 = BLUE;
    ledColor3 = BLUE;
  }

  if(requiresAuthentication != currentRequiresAuthentication){
    invalidateLEDs();
    currentRequiresAuthentication = requiresAuthentication;
  }

  if(!authenticated){
    //Flash RFID LED
    //all other LEDs off
    
    setLED(1, OFF);
    setLED(2, OFF);
    setLED(3, OFF);
    for (int ring = 0; ring < RING_COUNT; ring++){
      clearRing(ring);
    }
    if(rfidLedCounter++ % 7 == 0){
      rfidLedState = !rfidLedState;
    }
    digitalWrite(RFID_LED, rfidLedState);
    return;
  }
  else{
    digitalWrite(RFID_LED, LOW);
  }

  
  // The rotary IRQ sets the flag rotary_counter to true
  // if the knob position has changed. We can use this flag
  // to do something in the main loop() each time there's
  // a change. We'll clear this flag when we're done, so
  // that we'll only do this if() once for each change.

  if (rotary_change)
  {
    rotary_change = false; // Clear flag

    //blink for visual feedback
    setLED(1, OFF);
    delay(10); //try not to make this too long, otherwise the Arduino will miss ticks
    setLED(1, ledColor);

    if(rotary_counter < COUNTER_MIN){
      rotary_counter = COUNTER_MIN;
    }
    else if(rotary_counter > COUNTER_MAX){
      rotary_counter = COUNTER_MAX;
    }

    Serial.print("rotary1: ");
    Serial.println(rotary_counter, DEC);
    
    ring1_counter_ledsOn = map(rotary_counter, COUNTER_MIN, COUNTER_MAX, 1, RING_PIXEL_COUNT);

    clearRing(0);
    for(uint16_t i=0; i<RING_PIXEL_COUNT; i++) {
      if(i < ring1_counter_ledsOn){
        setRingPixelColor(0, i, red);
//        rings.setPixelColor(i, red);
      }
    }
    rings.show();
  }

  if (rotary2_change)
  {
    rotary2_change = false; // Clear flag

    //blink for visual feedback
    setLED(2, OFF);
    delay(10); //try not to make this too long, otherwise the Arduino will miss ticks
    setLED(2, ledColor);

    if(rotary2_counter < COUNTER_MIN){
      rotary2_counter = COUNTER_MIN;
    }
    else if(rotary2_counter > COUNTER_MAX){
      rotary2_counter = COUNTER_MAX;
    }
    Serial.print("rotary2: ");
    Serial.println(rotary2_counter, DEC);
    
    ring2_counter_ledsOn = map(rotary2_counter, COUNTER_MIN, COUNTER_MAX, 1, RING_PIXEL_COUNT);

    clearRing(1);
    for(uint16_t i=0; i<RING_PIXEL_COUNT; i++) {
      if(i < ring2_counter_ledsOn){
        setRingPixelColor(1, i, red);
      }
    }
    rings.show();
  }

  if (rotary3_change)
  {
    
    rotary3_change = false; // Clear flag

    //blink for visual feedback
    setLED(3, OFF);
    delay(10); //try not to make this too long, otherwise the Arduino will miss ticks
    setLED(3, ledColor);

    if(rotary3_counter < COUNTER_MIN){
      rotary3_counter = COUNTER_MIN;
    }
    else if(rotary3_counter > COUNTER_MAX){
      rotary3_counter = COUNTER_MAX;
    }

    Serial.print("rotary3: ");
    Serial.println(rotary3_counter, DEC);
    ring3_counter_ledsOn = map(rotary3_counter, COUNTER_MIN, COUNTER_MAX, 1, RING_PIXEL_COUNT);
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

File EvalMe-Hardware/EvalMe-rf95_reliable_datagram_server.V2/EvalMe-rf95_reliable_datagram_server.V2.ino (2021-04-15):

// rf95_reliable_datagram_server.pde
// -*- mode: C++ -*-
// Example sketch showing how to create a simple addressed, reliable messaging server
// with the RHReliableDatagram class, using the RH_RF95 driver to control a RF95 radio.
// It is designed to work with the other example rf95_reliable_datagram_client
// Tested with Anarduino MiniWirelessLoRa, Rocket Scream Mini Ultra Pro with the RFM95W 

#include <RHReliableDatagram.h>
#include <RH_RF95.h>
#include <SPI.h>

#define CLIENT_ADDRESS 5
#define SERVER_ADDRESS 3

// Singleton instance of the radio driver
RH_RF95 driver;
//RH_RF95 driver(5, 2); // Rocket Scream Mini Ultra Pro with the RFM95W

// Class to manage message delivery and receipt, using the driver declared above
RHReliableDatagram manager(driver, SERVER_ADDRESS);

// Need this on Arduino Zero with SerialUSB port (eg RocketScream Mini Ultra Pro)
//#define Serial SerialUSB

String inputString = "";         // a String to hold incoming data
bool stringComplete = false;  // whether the string is complete

void setup() 
{
  // Rocket Scream Mini Ultra Pro with the RFM95W only:
  // Ensure serial flash is not interfering with radio communication on SPI bus
//  pinMode(4, OUTPUT);
//  digitalWrite(4, HIGH);

  Serial.begin(9600);
  
  // reserve 200 bytes for the inputString:
  inputString.reserve(200);
  
  while (!Serial) ; // Wait for serial port to be available
  if (!manager.init())
    Serial.println(F("#TYPE:INFO;DATA:LORA_init_failed"));
  // Defaults after init are 434.0MHz, 13dBm, Bw = 125 kHz, Cr = 4/5, Sf = 128chips/symbol, CRC on

  // The default transmitter power is 13dBm, using PA_BOOST.
  // If you are using RFM95/96/97/98 modules which uses the PA_BOOST transmitter pin, then 
  // you can set transmitter powers from 5 to 23 dBm:
//  driver.setTxPower(23, false);
  // If you are using Modtronix inAir4 or inAir9,or any other module which uses the
  // transmitter RFO pins and not the PA_BOOST pins
  // then you can configure the power transmitter power for -1 to 14 dBm and with useRFO true. 
  // Failure to do that will result in extremely low transmit powers.
//  driver.setTxPower(14, true);
  // You can optionally require this module to wait until Channel Activity
  // Detection shows no activity on the channel before transmitting by setting
  // the CAD timeout to non-zero:
//  driver.setCADTimeout(10000);
  Serial.println(F("#TYPE:INFO;DATA:LORA_SERVER_started"));
}

uint8_t data[] = "Data received!";
// Dont put this on the stack:
uint8_t buf[RH_RF95_MAX_MESSAGE_LEN];

uint8_t ctrl_requireAuth[] = "REQUIRE_AUTH";
uint8_t ctrl_requireNoAuth[] = "REQUIRE_NO_AUTH";

uint8_t ctrl_SetCounterStart[] = "SET_COUNTER";
uint8_t ctrl_SetMin1[] = "SET_COUNTER_MIN:1";

uint8_t ctrl_SetMax3[] = "SET_COUNTER_MAX:03"; //-253
uint8_t ctrl_SetMax4[] = "SET_COUNTER_MAX:04";
uint8_t ctrl_SetMax5[] = "SET_COUNTER_MAX:05";
uint8_t ctrl_SetMax7[] = "SET_COUNTER_MAX:07";
uint8_t ctrl_SetMax10[] = "SET_COUNTER_MAX:10";
uint8_t ctrl_SetMax12[] = "SET_COUNTER_MAX:12"; //-244

void loop()
{
  if (manager.available())
  {
    // Wait for a message addressed to us from the client
    uint8_t len = sizeof(buf);
    uint8_t from;
    if (manager.recvfromAck(buf, &len, &from))
    {
      Serial.print(F("#TYPE:INCOMING;FROM:0x"));
      Serial.print(from, HEX);
      Serial.print(";");
      Serial.println((char*)buf);

      // Send a reply back to the originator client
      if (!manager.sendtoWait(data, sizeof(data), from))
        Serial.println(F("#TYPE:ERROR;DATA:sendtoWait failed"));
    }
  }

  // print the string when a newline arrives:
  if (stringComplete) {
    Serial.print("Serial incoming: ");
    Serial.println(inputString);
    
    if(inputString.startsWith("REQUIRE_AUTH")){
      if (!manager.sendtoWait(ctrl_requireAuth, sizeof(ctrl_requireAuth), CLIENT_ADDRESS))
        Serial.println(F("#TYPE:ERROR;DATA:sendtoWait REQUIRE_AUTH failed"));
      else
        Serial.println(F("#TYPE:OK;DATA:REQUIRE_AUTH sent"));
    }
    else if(inputString.startsWith("REQUIRE_NO_AUTH")){
      if (!manager.sendtoWait(ctrl_requireNoAuth, sizeof(ctrl_requireNoAuth), CLIENT_ADDRESS))
        Serial.println(F("#TYPE:ERROR;DATA:sendtoWait REQUIRE_NO_AUTH failed"));
      else
        Serial.println(F("#TYPE:OK;DATA:REQUIRE_NO_AUTH sent"));
    }
    else if(inputString.startsWith("SET_COUNTER_MAX:")){
//      String count = inputString.substring(16);
//      Serial.print(F("new max count: "));
//      Serial.println(count);

      uint8_t ctrl_SetMax[] = "SET_COUNTER_MAX:12";
      if(inputString.startsWith("SET_COUNTER_MAX:03")){
        memcpy( ctrl_SetMax, ctrl_SetMax3, sizeof(ctrl_SetMax3) );
      }
      else if(inputString.startsWith("SET_COUNTER_MAX:04")){
        memcpy( ctrl_SetMax, ctrl_SetMax4, sizeof(ctrl_SetMax4) );
      }
      else if(inputString.startsWith("SET_COUNTER_MAX:05")){
        memcpy( ctrl_SetMax, ctrl_SetMax5, sizeof(ctrl_SetMax5) );
      }
      else if(inputString.startsWith("SET_COUNTER_MAX:07")){
        memcpy( ctrl_SetMax, ctrl_SetMax7, sizeof(ctrl_SetMax7) );
      }
      else if(inputString.startsWith("SET_COUNTER_MAX:10")){
        memcpy( ctrl_SetMax, ctrl_SetMax10, sizeof(ctrl_SetMax10) );
      }
      else if(inputString.startsWith("SET_COUNTER_MAX:12")){
        memcpy( ctrl_SetMax, ctrl_SetMax12, sizeof(ctrl_SetMax12) );
      }
      if (!manager.sendtoWait(ctrl_SetMax, sizeof(ctrl_SetMax), CLIENT_ADDRESS))
        Serial.println("#TYPE:ERROR;DATA:sendtoWait SET_COUNTER_MAX failed");
      else{
        Serial.println("#TYPE:OK;DATA:SET_COUNTER_MAX sent");
//        Serial.println(ctrl_SetMax);
      }
    }
    else if(inputString.startsWith("SET_COUNTER_MIN:")){
      String count = inputString.substring(16);
      Serial.print("new min count: ");
      Serial.println(count);
      if (!manager.sendtoWait(ctrl_requireNoAuth, sizeof(ctrl_requireNoAuth), CLIENT_ADDRESS))
        Serial.println(F("#TYPE:ERROR;DATA:sendtoWait SET_COUNTER_MIN failed"));
      else
        Serial.println(F("#TYPE:OK;DATA:SET_COUNTER_MIN sent"));
    }
    
    // clear the string:
    inputString = "";
    stringComplete = false;
  }
}

/*
  SerialEvent occurs whenever a new data comes in the hardware serial RX. This
  routine is run between each time loop() runs, so using delay inside loop can
  delay response. Multiple bytes of data may be available.
*/
void serialEvent() {
  while (Serial.available()) {
    // get the new byte:
    char inChar = (char)Serial.read();
    // add it to the inputString:
    inputString += inChar;
    // if the incoming character is a newline, set a flag so the main loop can
    // do something about it:
    if (inChar == '\n') {
      stringComplete = true;
    }
  }
}

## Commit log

2020-02-06 fixed: hide set fixed: count 0 responses correctly new: add dpPath in debug view
    [main.js]
2020-02-06 fixed: filter duplicate votes when using RFID new: open DB path when clicking on it in debug view
    [main.js]
2021-04-15 Add documentation
    [U_Box_V103.back.V1.stl, U_Box_V103.bottom.V2-only logo.stl, U_Box_V103.bottom.V2-without logo.stl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]
